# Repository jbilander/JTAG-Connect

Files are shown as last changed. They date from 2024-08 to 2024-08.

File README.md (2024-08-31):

# JTAG-Connect
USB-blaster programming the intel/altera FPGA using a DIY spring clip with pogo-pins that clips onto a standard 2.0 mm pin pitch JTAG SMD-footprint:

<br />
<a href="images/JTAG_connect_pic1.jpg">
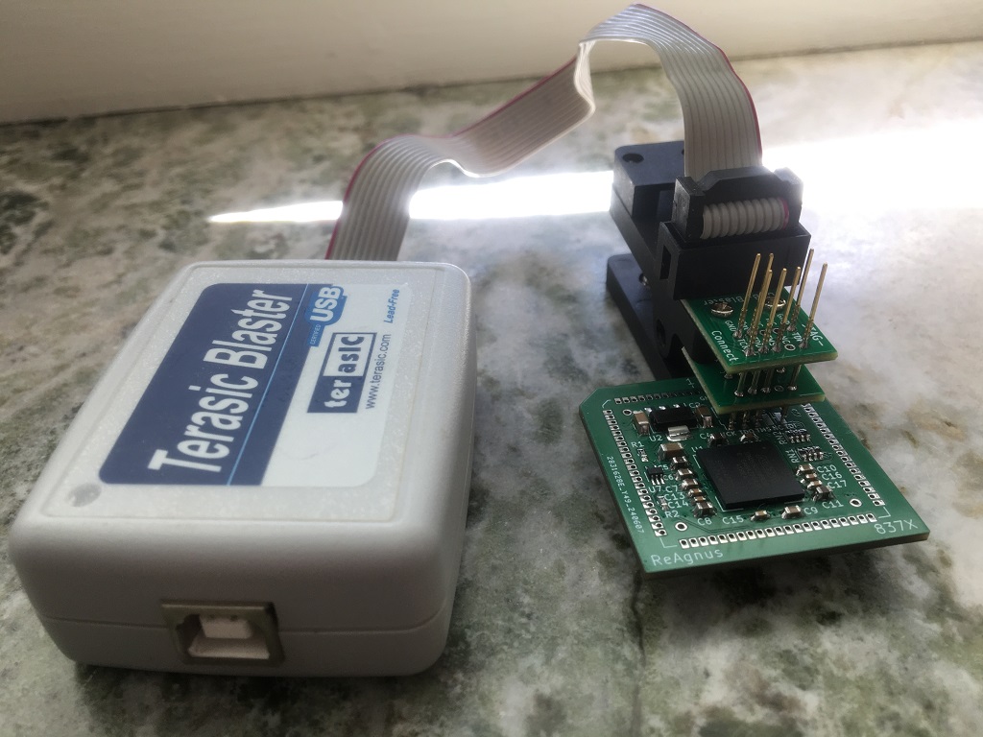
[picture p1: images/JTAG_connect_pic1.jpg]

</a>
<br />
<a href="images/JTAG_connect_pic2.jpg">
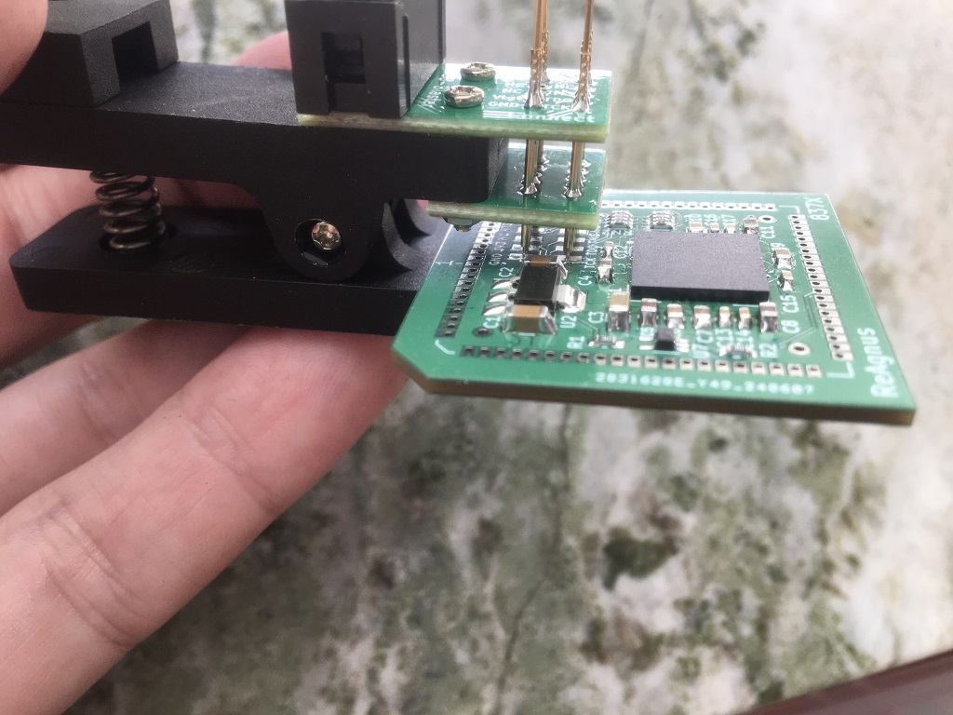
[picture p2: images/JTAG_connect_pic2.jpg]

</a>
<a href="images/JTAG_connect_pic3.jpg">
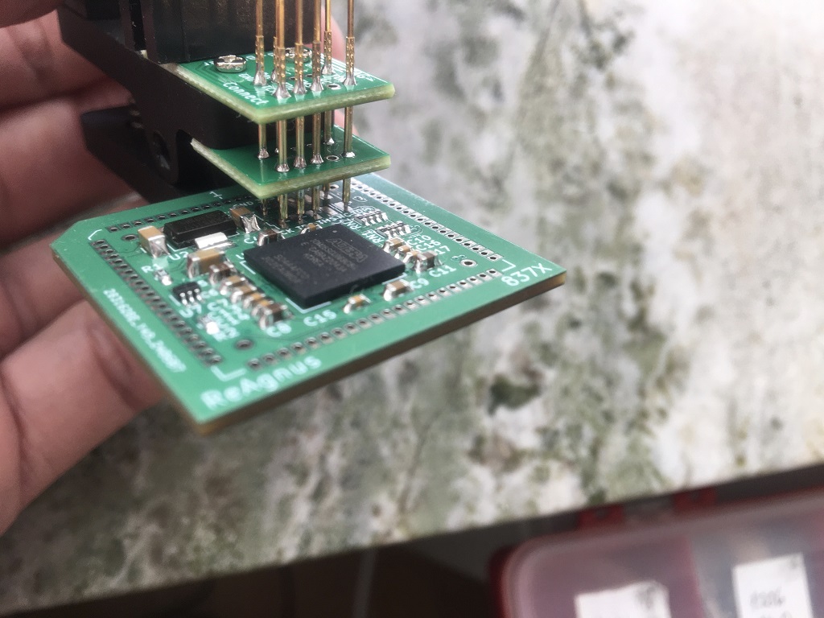
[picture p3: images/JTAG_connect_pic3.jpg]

</a>

***

video with the spring clip in action:<br />
https://drive.google.com/file/d/1q0D7EuQR9gsi54iwchI4ziomZzsiyqWE/view?usp=sharing

I have spare PCBs in case anyone is interested in this, or I can make to order for a fiver + shipping (until my spares are depleted) in case anyone can't build themselves. You will have to source the DIY clip (including screws) yourself from [aliexpress](https://www.aliexpress.com/item/1005004383076344.html) or similar.<br />
my email: jorgen.bilander at gmail com
<br />

The receptacle pogo pin socket I use, R50-3W:
https://www.aliexpress.com/item/1005003512878045.html

The pogo pin I use, P50-Q1:
https://www.aliexpress.com/item/1005002199072447.html

***
Connector pinout:

<a href="images/JTAG_connector_pinout.jpg">
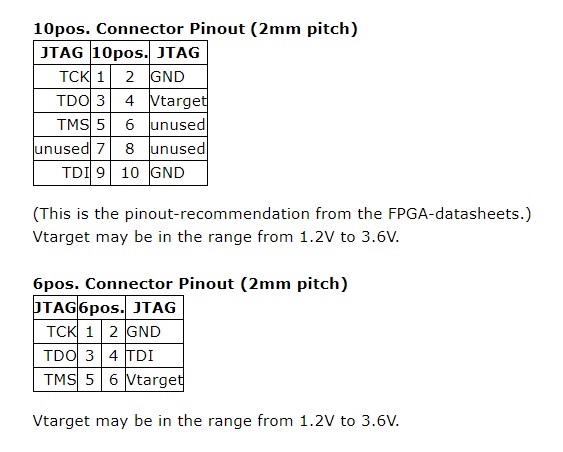
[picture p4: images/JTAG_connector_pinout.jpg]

</a>

***

<a href="images/JTAG_connect_screenshot.png">
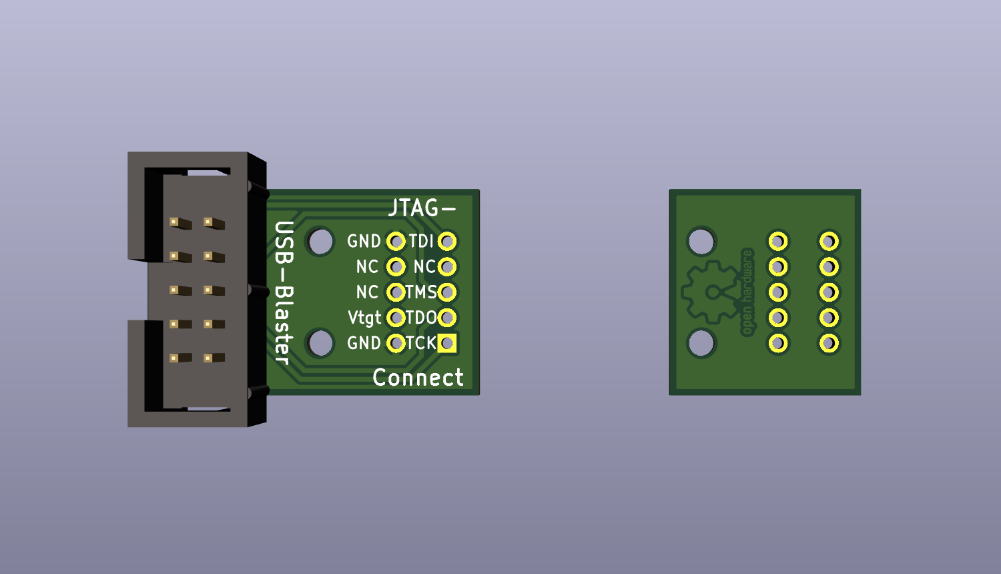
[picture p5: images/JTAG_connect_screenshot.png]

</a>

Designed for the common DIY spring clip plenty available on AliExpress:

<a href="images/DIY_spring_clip_kit.jpg">
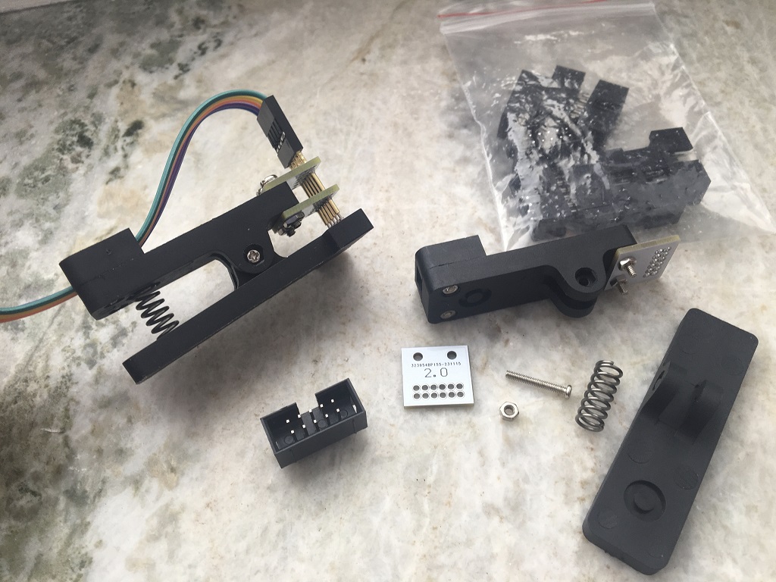
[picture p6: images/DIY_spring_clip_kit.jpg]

</a>

***

The 6-pin handheld version:

<a href="images/JTAG_connect_pic15.jpg">
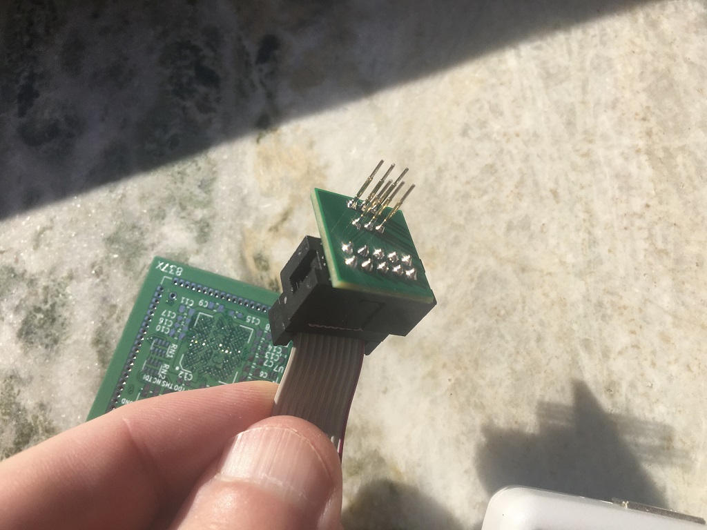
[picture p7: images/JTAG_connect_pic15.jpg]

</a>
<a href="images/JTAG_connect_pic16.jpg">
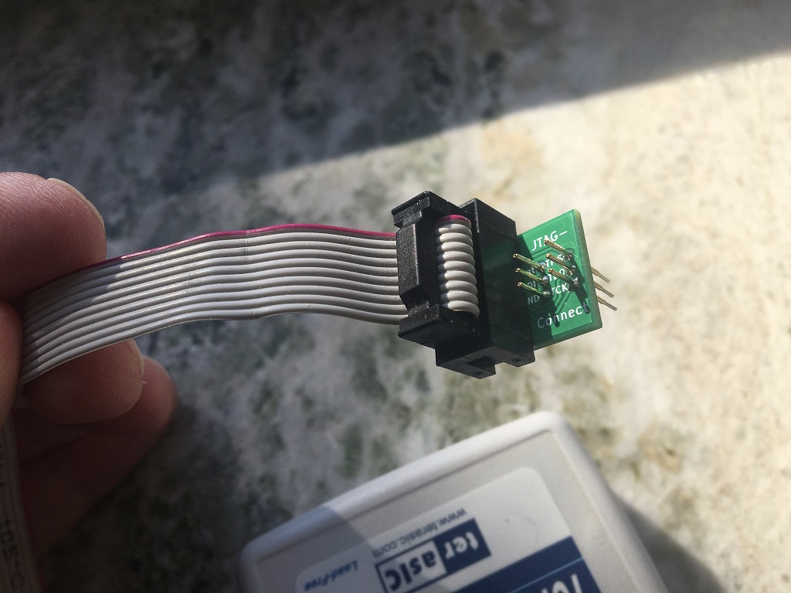
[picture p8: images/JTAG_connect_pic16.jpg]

</a>
</a>
<a href="images/JTAG_connect_pic17.jpg">
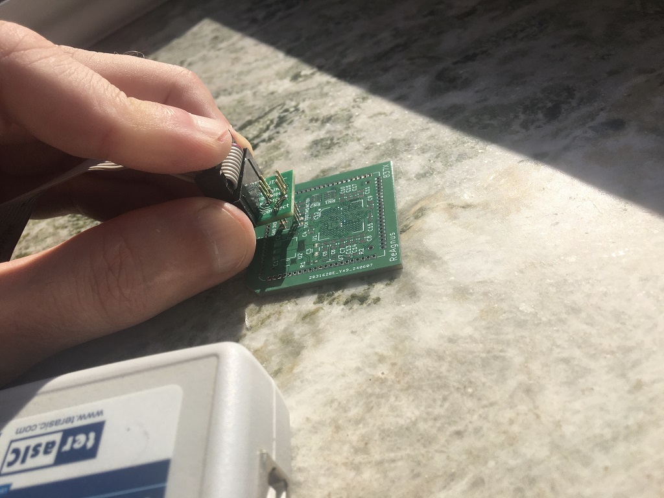
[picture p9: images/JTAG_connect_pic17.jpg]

</a>

***

A PCB panel also with a 6-pin version and handheld versions of the two:

<a href="images/PCB_panel_RevA_screenshot.png">
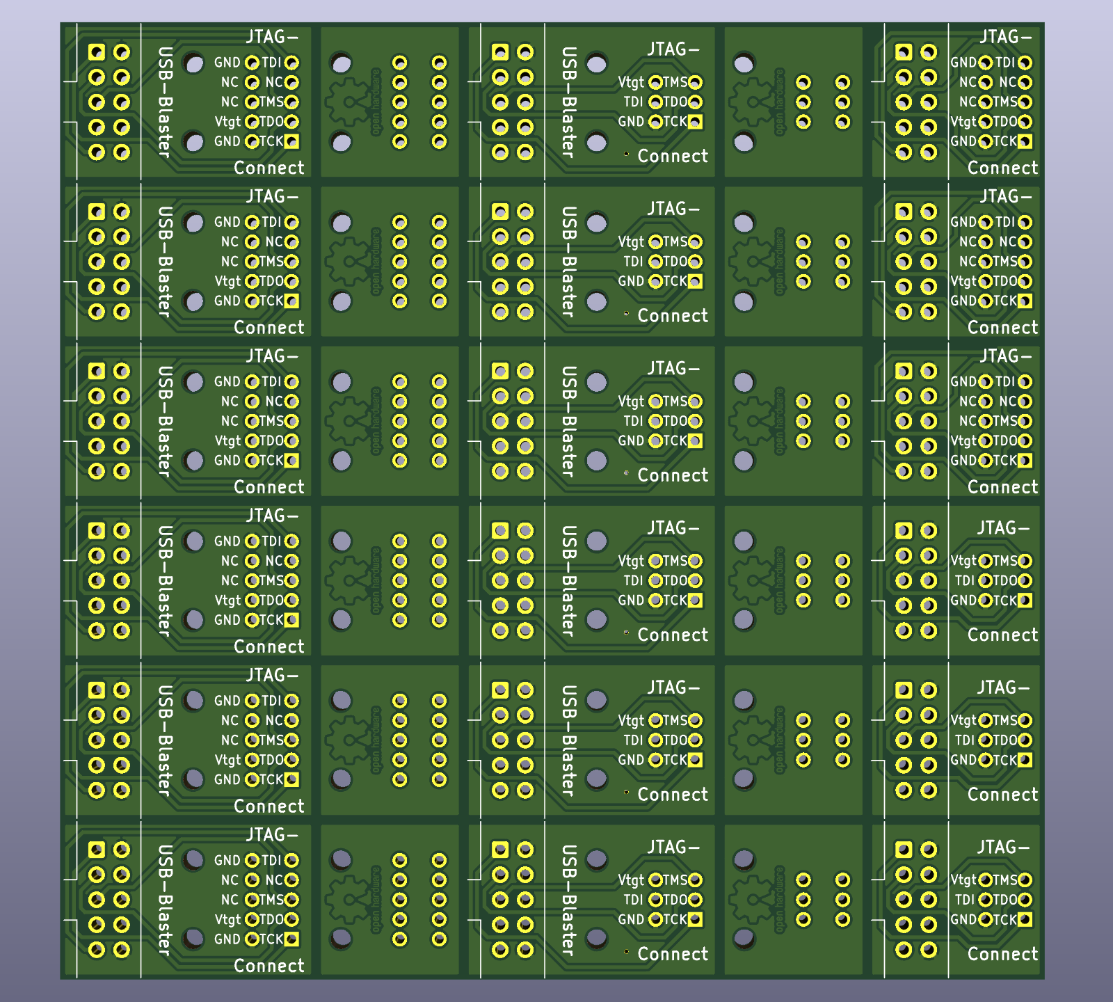
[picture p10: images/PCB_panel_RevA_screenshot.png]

</a>
<a href="images/V-cuts_screenshot.png">
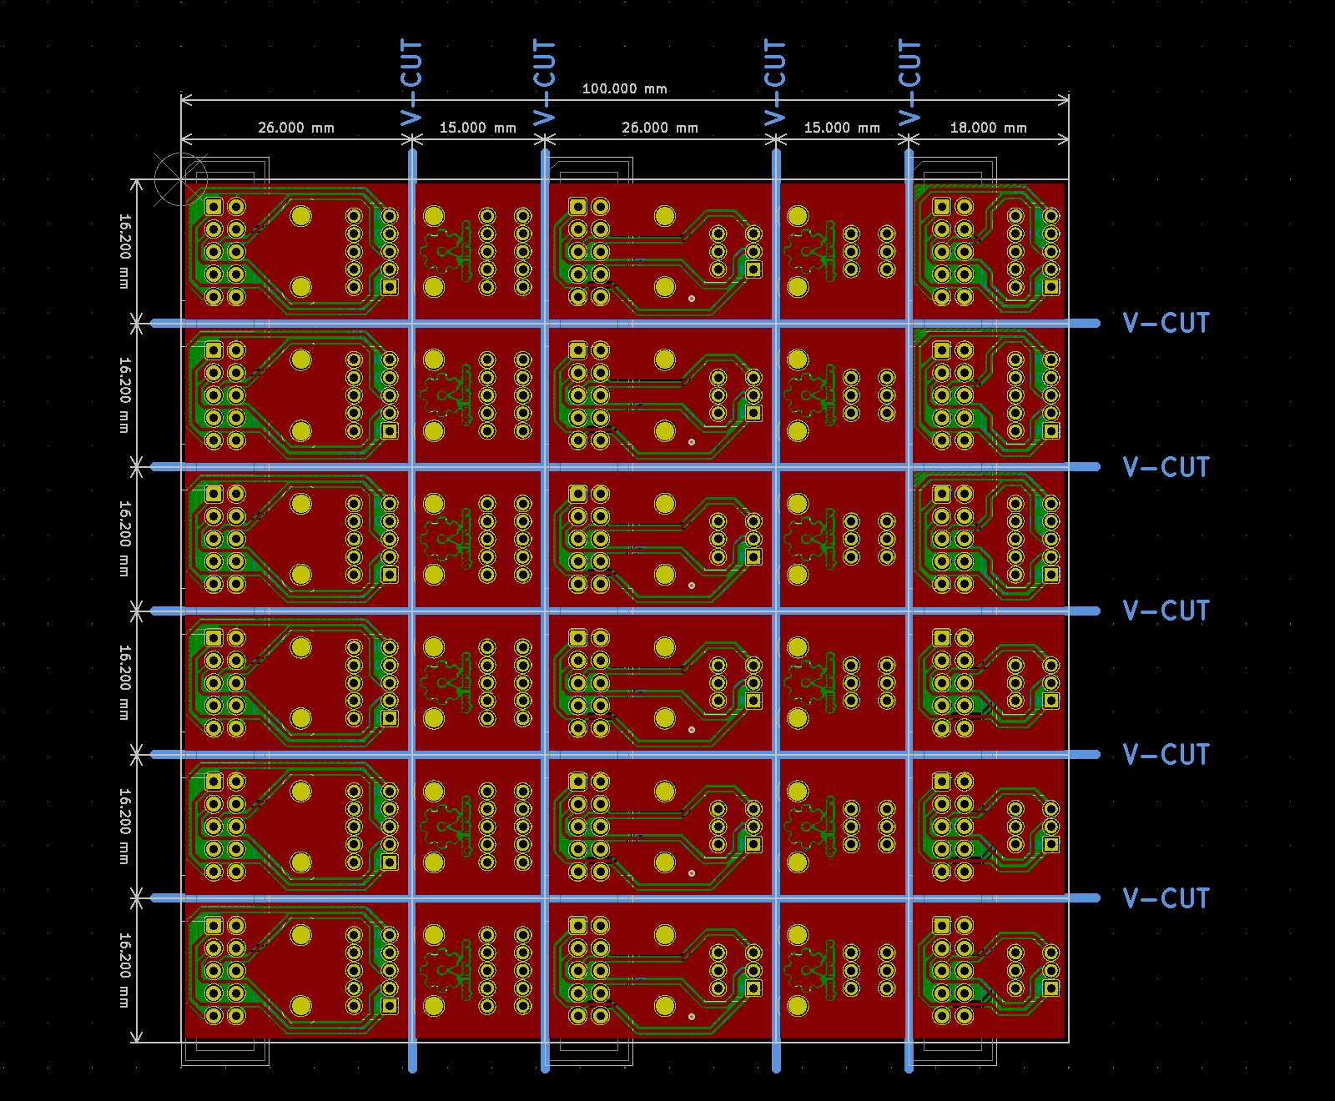
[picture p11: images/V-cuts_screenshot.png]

</a>

***

When ordering from JLCPCB select:

Delivery Format: 

    Panel by Customer

Remove Order Number: 

    Specify a location

This will notify JLC where to put the order number, they will replace the "JLCJLCJLCJLC" silkscreen label.

And write a comment about V-scoring is specified on the User-Comment layer.

***

### Soldering the DIY clip PCBs:

<a href="images/JTAG_connect_pic4.jpg">
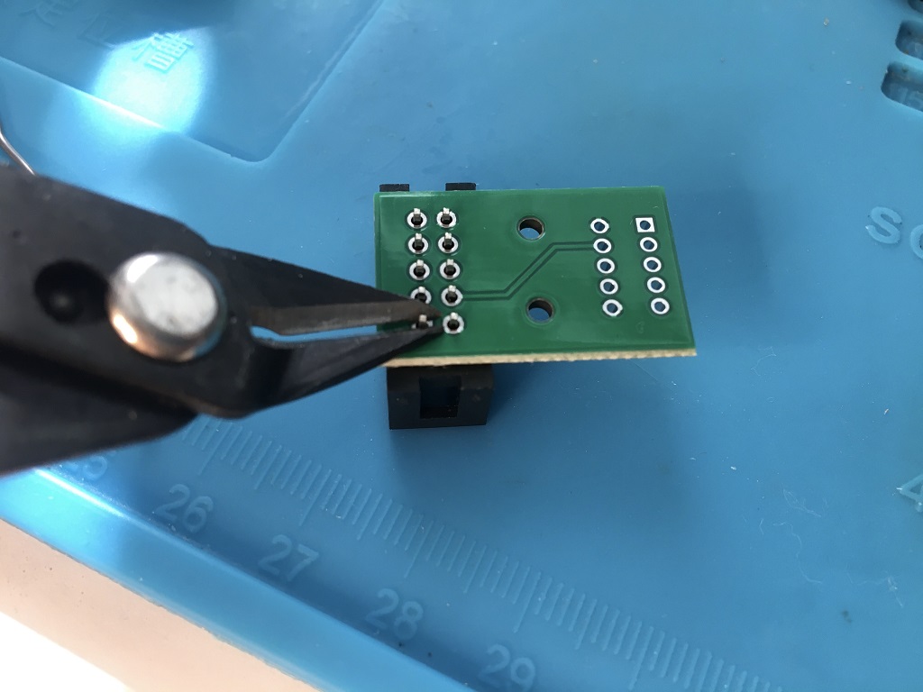
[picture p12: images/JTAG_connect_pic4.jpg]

</a>
<a href="images/JTAG_connect_pic5.jpg">
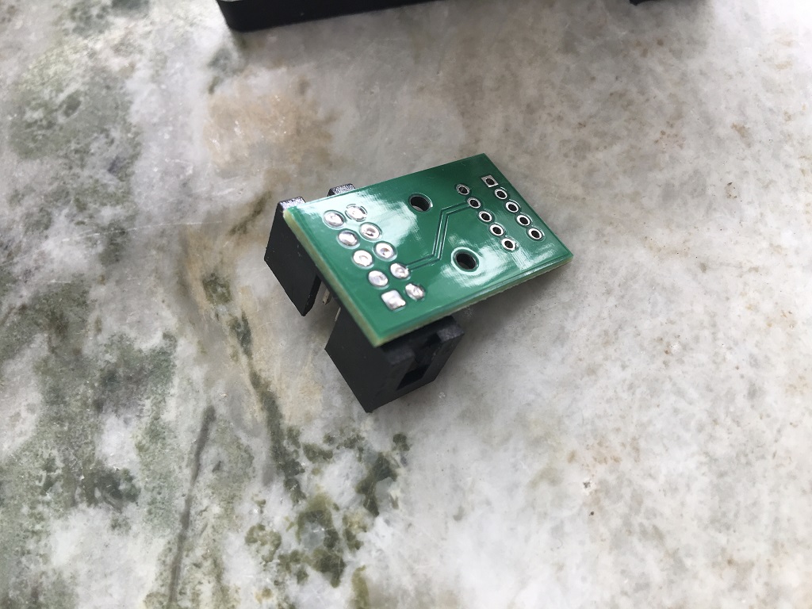
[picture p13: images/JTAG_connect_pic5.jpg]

</a>
<a href="images/JTAG_connect_pic6.jpg">
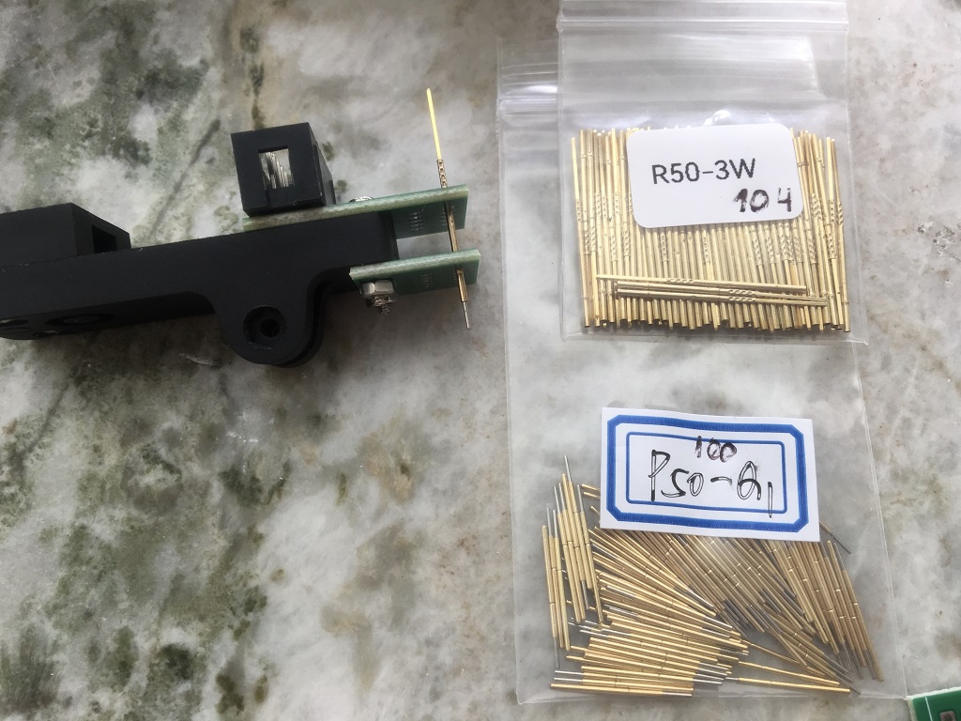
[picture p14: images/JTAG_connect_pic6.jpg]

</a>
<br />
Start with the back row (it will be easier to solder) and you can use a 2.0 mm pin pitch connector as a Jig to get the square top pins aligned.<br /> 
<a href="images/JTAG_connect_pic7.jpg">
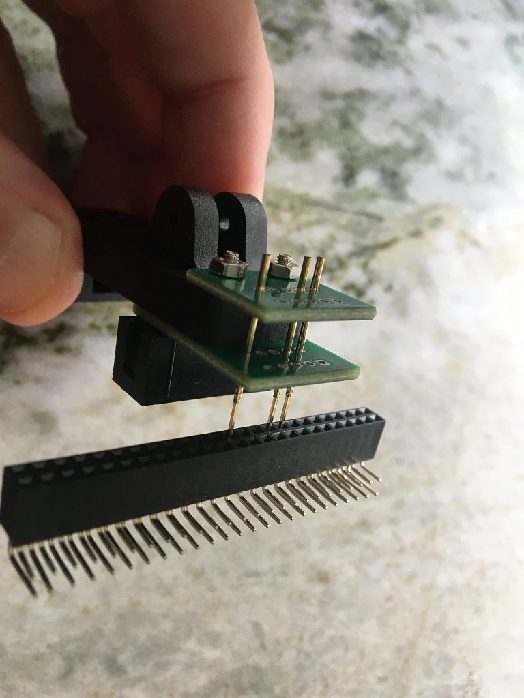
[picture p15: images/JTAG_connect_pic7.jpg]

</a>
<br />
<a href="images/JTAG_connect_pic8.jpg">
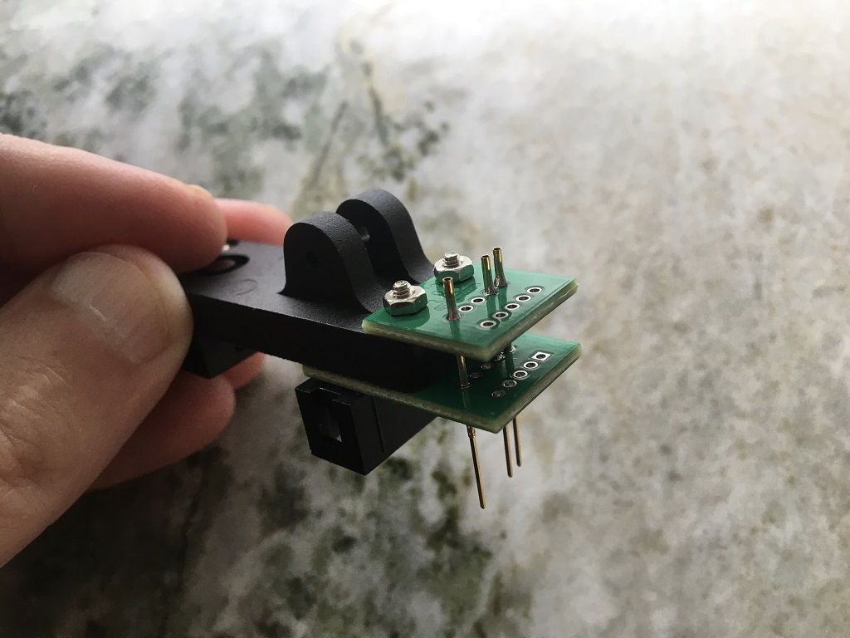
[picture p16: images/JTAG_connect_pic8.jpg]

</a>
<a href="images/JTAG_connect_pic9.jpg">
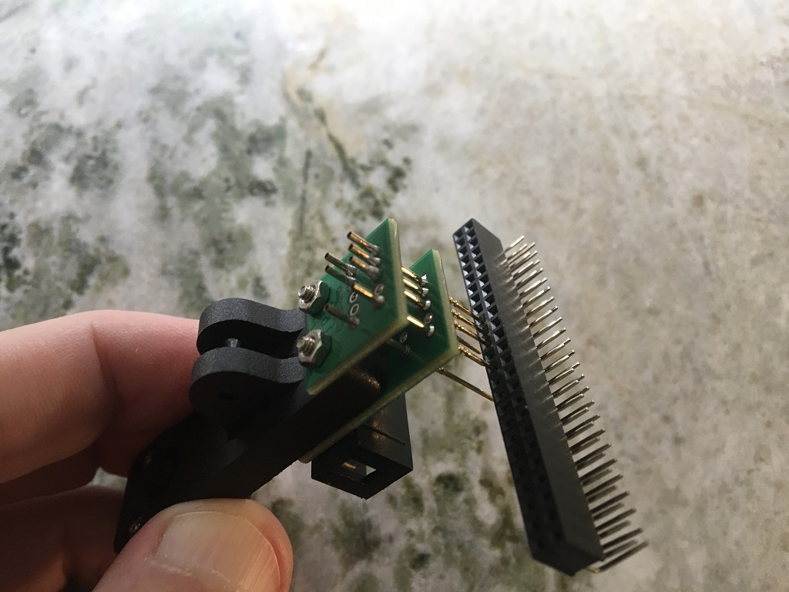
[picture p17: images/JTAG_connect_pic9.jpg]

</a>
</a>
<a href="images/JTAG_connect_pic10.jpg">
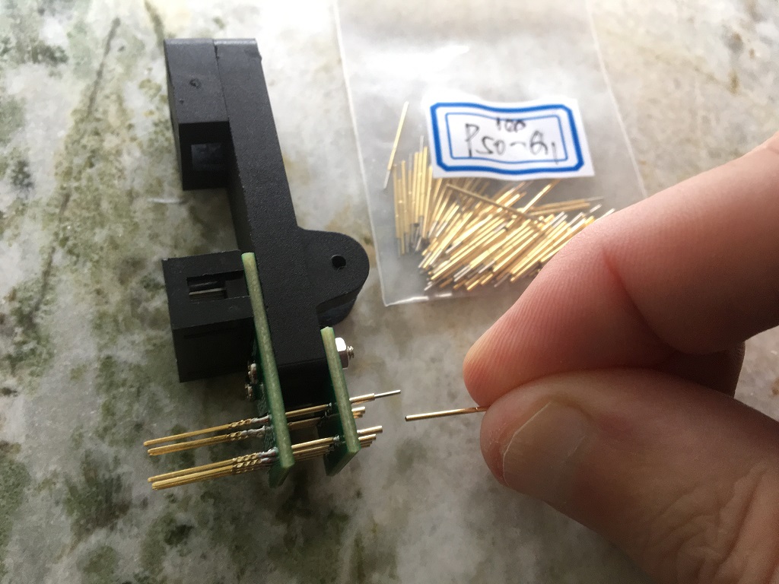
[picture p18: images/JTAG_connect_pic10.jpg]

</a>

### Soldering the Handheld version:

I used a 2.0 mm pin pitch connector as a Jig to hold the pins in place at a nice consistent distance:

<a href="images/JTAG_connect_pic11.jpg">
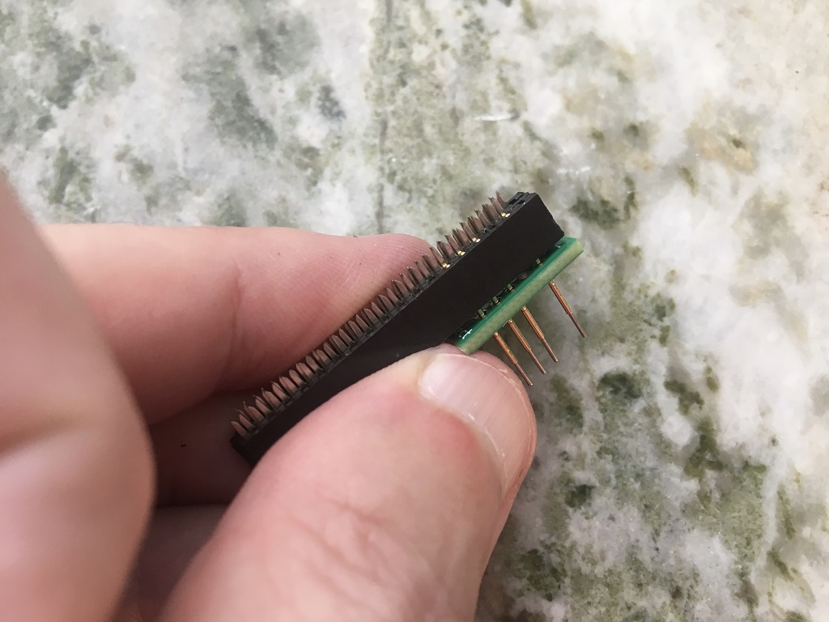
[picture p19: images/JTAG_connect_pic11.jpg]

</a>
<a href="images/JTAG_connect_pic12.jpg">
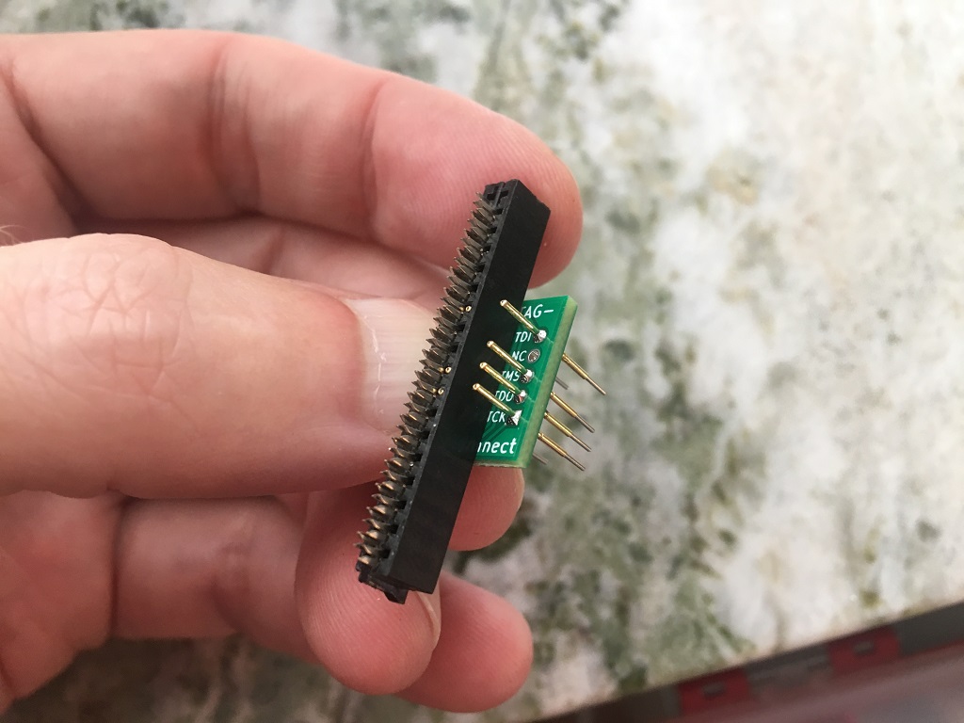
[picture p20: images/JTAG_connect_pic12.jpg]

</a>
</a>
<a href="images/JTAG_connect_pic13.jpg">
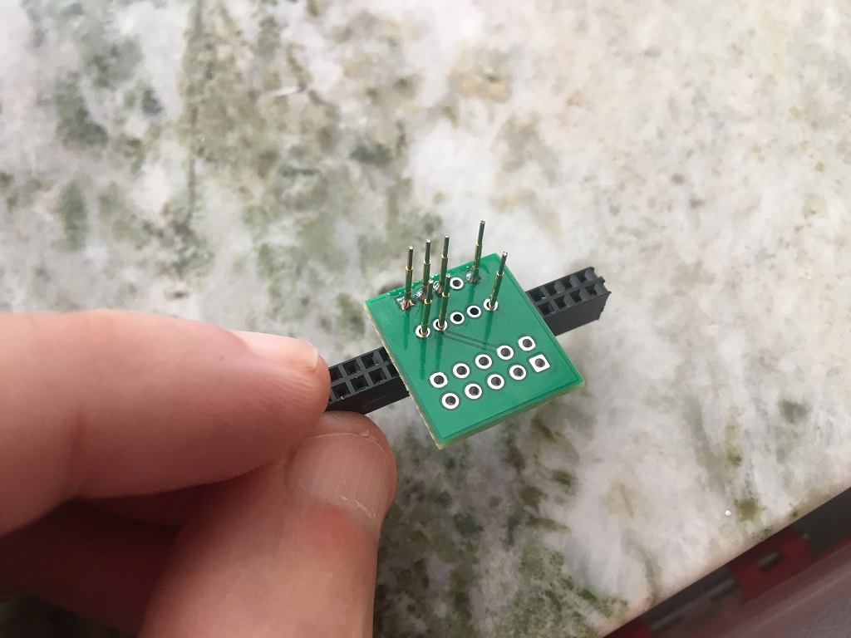
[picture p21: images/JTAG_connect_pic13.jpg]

</a>
<br />
<a href="images/JTAG_connect_pic14.jpg">
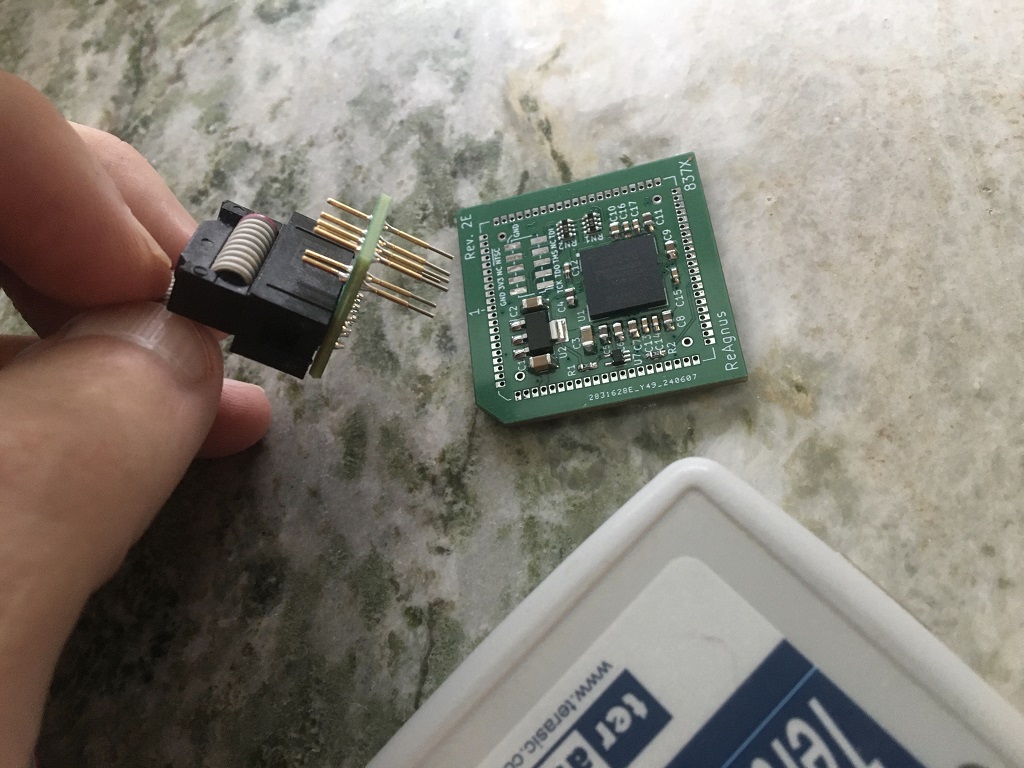
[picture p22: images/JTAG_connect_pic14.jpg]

</a>

***

[][cc-by-sa]

This work is licensed under a
[Creative Commons Attribution-ShareAlike 4.0 International License][cc-by-sa].

[][cc-by-sa]

[cc-by-sa]: http://creativecommons.org/licenses/by-sa/4.0/
[cc-by-sa-image]: https://licensebuttons.net/l/by-sa/4.0/88x31.png
[cc-by-sa-shield]: https://img.shields.io/badge/License-CC%20BY--SA%204.0-lightgrey.svg

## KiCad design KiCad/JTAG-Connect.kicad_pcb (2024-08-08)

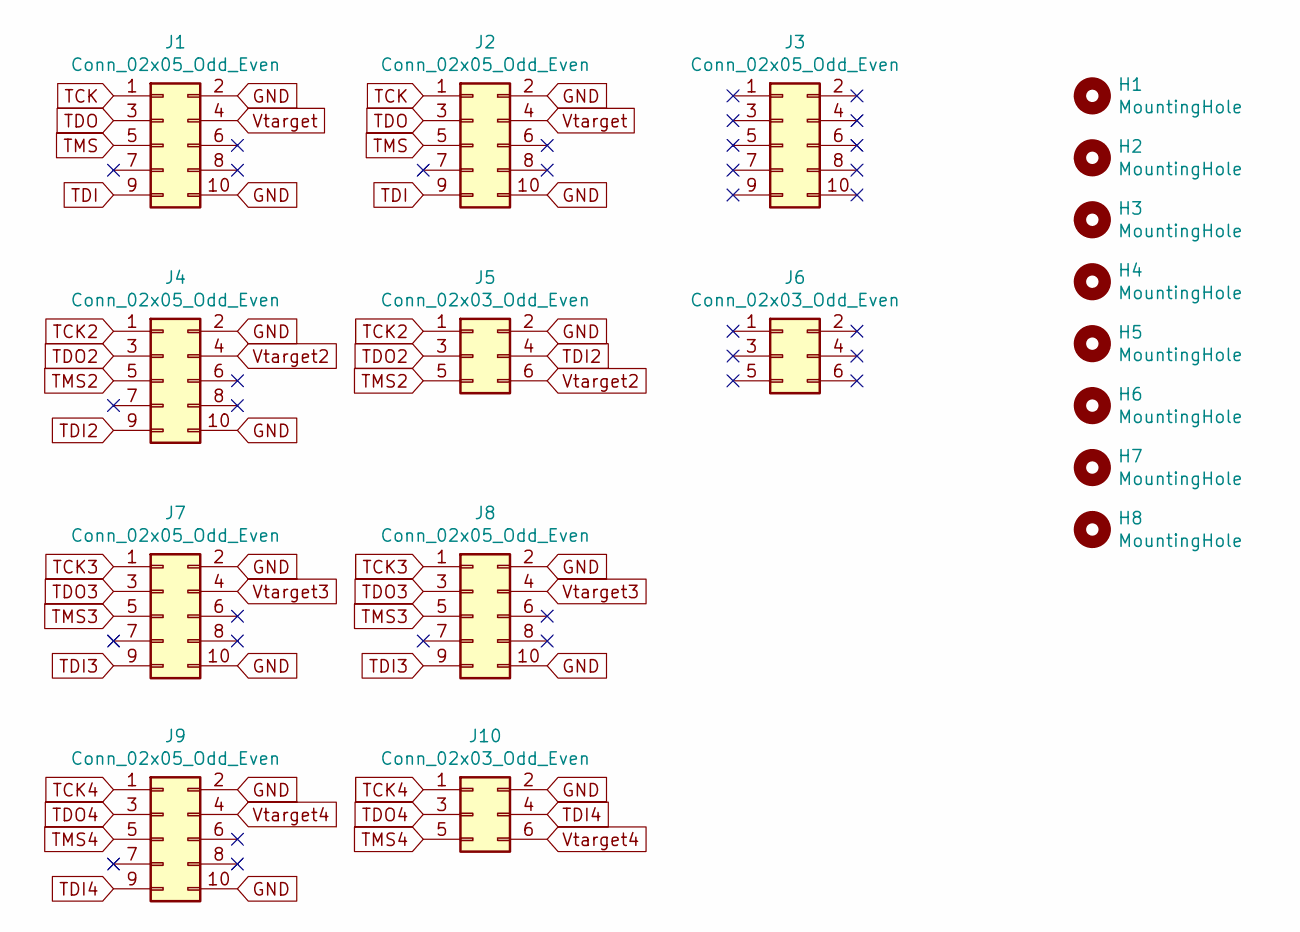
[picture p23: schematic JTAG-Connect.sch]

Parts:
H1, H2, H3, H4, H5, H6, H7, H8: MountingHole; MountingHole_2mm
J1, J4, J7, J9: Conn_02x05_Odd_Even; IDC-Header_2x05_P2.54mm_Vertical
J2, J3, J8: Conn_02x05_Odd_Even; PinHeader_2x05_P2.00mm_JTAG_connect_on_SMD_pads
J5, J6, J10: Conn_02x03_Odd_Even; PinHeader_2x03_P2.00mm_JTAG_connect_on_SMD_pads

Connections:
GND: J1.2, J1.10, J2.2, J2.10, J4.2, J4.10, J5.2, J7.2, J7.10, J8.2, J8.10, J9.2, J9.10, J10.2
TCK: J1.1, J2.1
TCK2: J4.1, J5.1
TCK3: J7.1, J8.1
TCK4: J9.1, J10.1
TDI: J1.9, J2.9
TDI2: J4.9, J5.4
TDI3: J7.9, J8.9
TDI4: J9.9, J10.4
TDO: J1.3, J2.3
TDO2: J4.3, J5.3
TDO3: J7.3, J8.3
TDO4: J9.3, J10.3
TMS: J1.5, J2.5
TMS2: J4.5, J5.5
TMS3: J7.5, J8.5
TMS4: J9.5, J10.5
Vtarget: J1.4, J2.4
Vtarget2: J4.4, J5.6
Vtarget3: J7.4, J8.4
Vtarget4: J9.4, J10.6

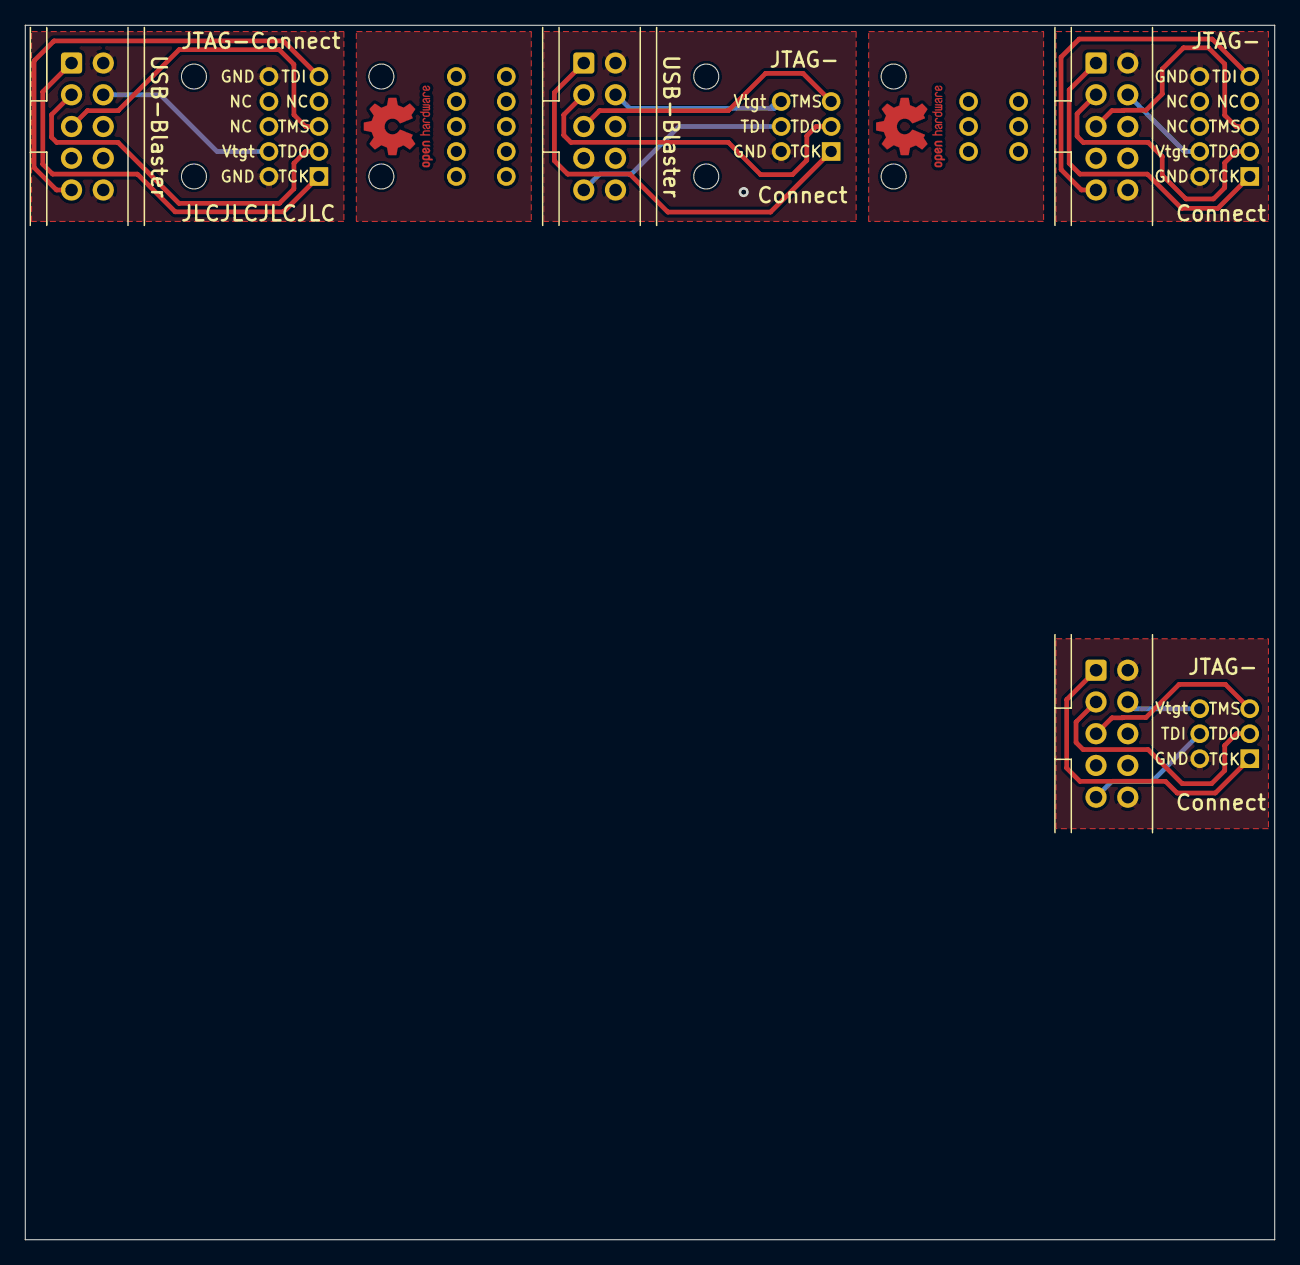
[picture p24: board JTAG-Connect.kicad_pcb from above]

Board: 2 copper layers, 100.0 x 97.2 mm, 18 parts (0 on the bottom side), 21 nets.

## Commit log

2024-07-25 Add KiCad files
    [JTAG-Connect.kicad_pcb, JTAG-Connect.sch]
2024-07-28 Add footprints
2024-07-28 updated design
    [JTAG-Connect.kicad_pcb, JTAG-Connect.sch]
2024-07-30 Increased OSHW-symbol text size
    [JTAG-Connect.kicad_pcb]
2024-08-08 Updated design to fit DIY spring clip.
    [JTAG-Connect.kicad_pcb, JTAG-Connect.sch]
2024-08-31 Add images of the 6-pin handheld version
2024-08-31 Add pic with connector pinout

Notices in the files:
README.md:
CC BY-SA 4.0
